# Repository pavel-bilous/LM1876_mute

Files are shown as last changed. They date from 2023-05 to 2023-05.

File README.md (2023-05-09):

# LM1876 mute delay

Circuit mutes LM1876 for 1 sec upon powering on. 

From the datasheet, if a logic high (1.5 to 5V) is applied to the MUTE pin, the amp will be muted.

The goal is to mute the amp during the turn on (and turn off). For that a logic high needs to be applied to the MUTE pin when amp is turned on, but after 1 or 2 seconds wait time the MUTE pin should be pulled low (< 1.5V).

Simple circuit that achieves the goal consists of:
* 5V zener regulator
* RC time delay
* NOT logic gate

Power is taken from the positive rail of the amp's power supply that is 20V to 25V.

Zener regulator resistor is selected at 10K, and it pulls ~2mA of current. Another 10K resistor is at the drain of the FET and pulls another ~2mA resulting in total current draw of ~4mA.

## PCB rendered in 3d:
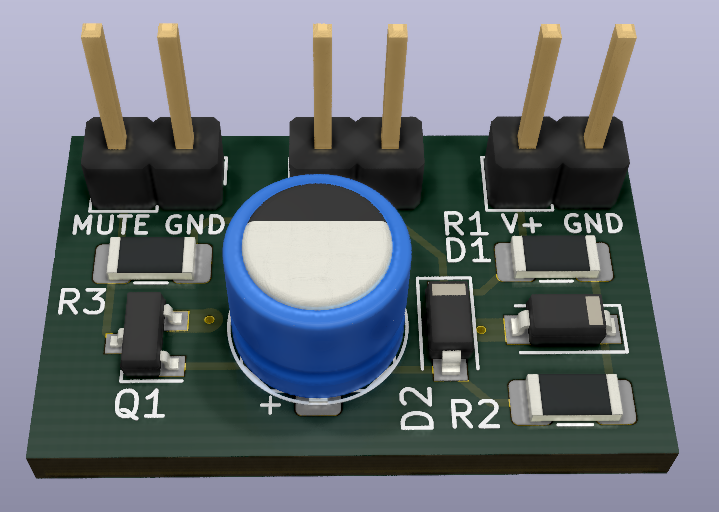
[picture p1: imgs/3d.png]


## Schematics
Only one 22uF capacitor needs to be used.
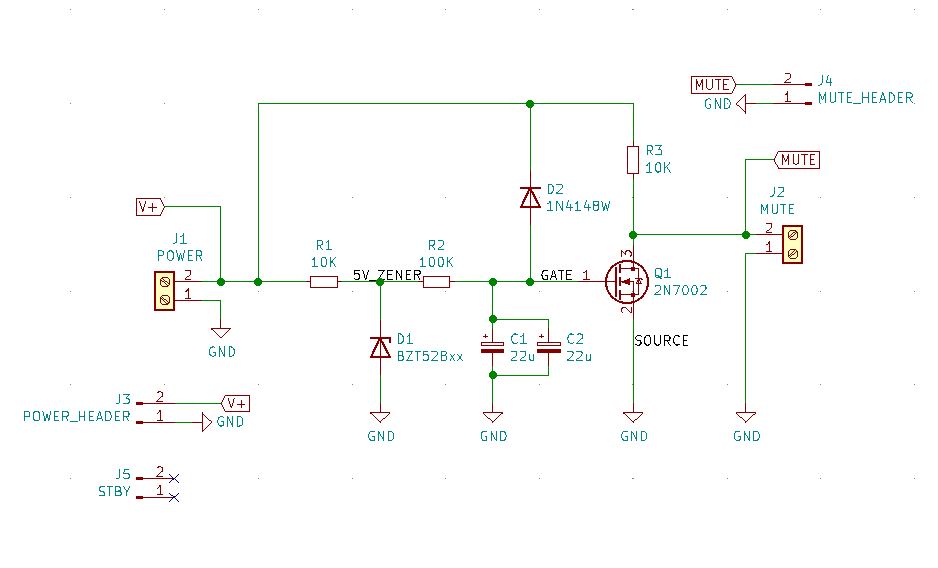
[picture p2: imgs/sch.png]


## PCB layout

Headers can be directly connected on top of the amplifier board in my other repository for LM1876 board.

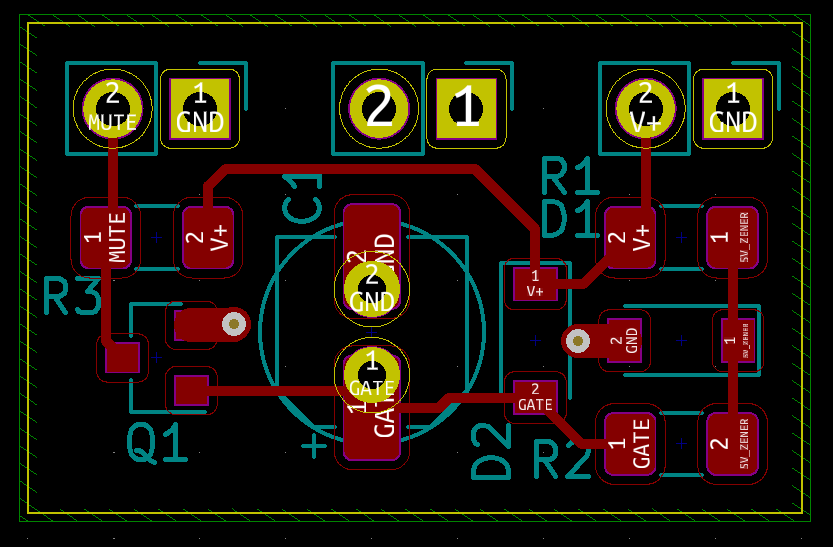
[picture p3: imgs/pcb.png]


## LTSpice simulation
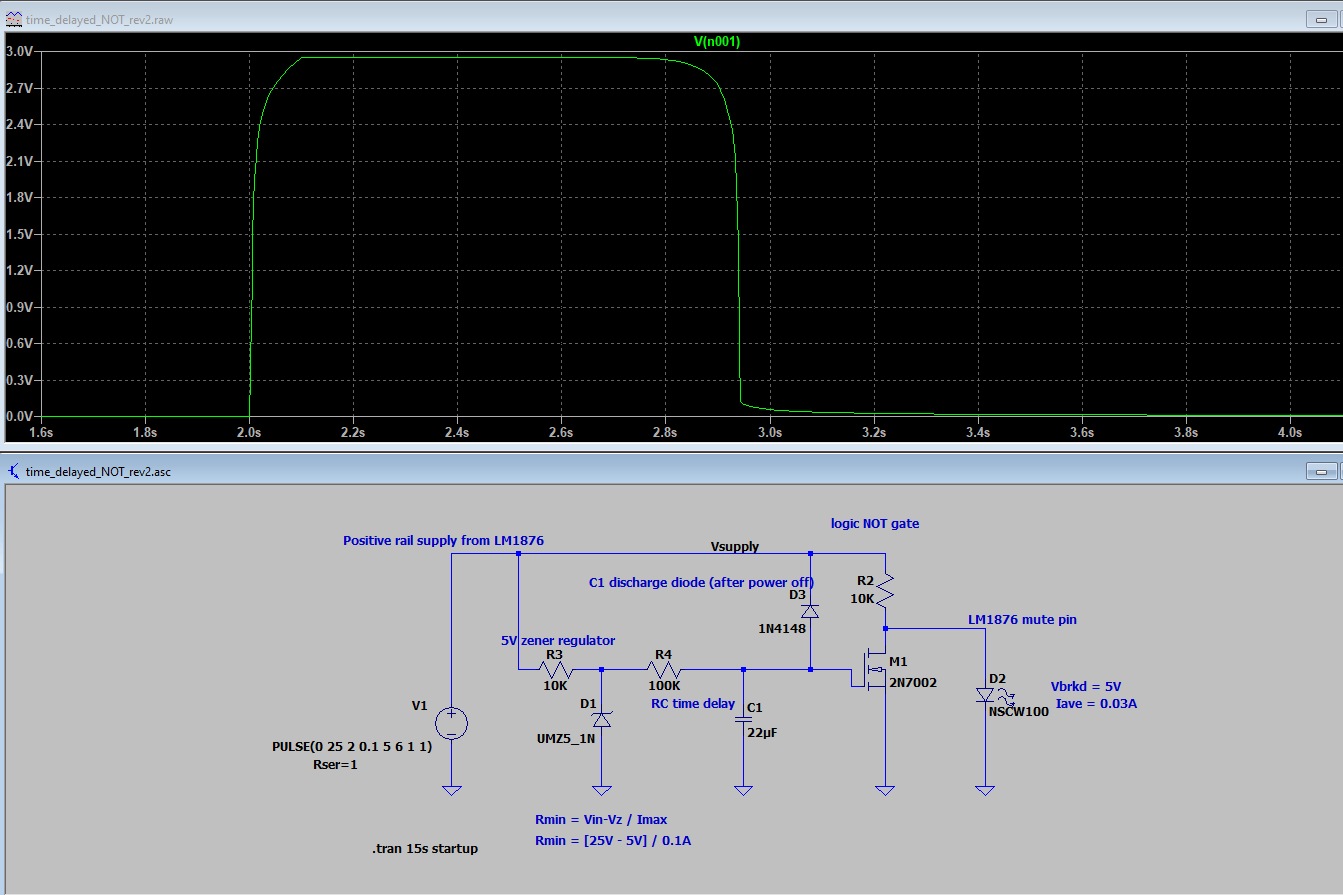
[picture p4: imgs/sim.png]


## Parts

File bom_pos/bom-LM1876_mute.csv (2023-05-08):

Id | Designator | Package | Quantity | Designation | Supplier and ref
1 | C2 | C_Radial_D6.3mm_H5.0mm_P2.50mm | 1 | 22u
2 | C1 | CP_Elec_5x5.4 | 1 | 22u
3 | J5 | PinHeader_1x02_P2.54mm_Vertical | 1 | STBY
4 | R3,R1 | R_1206_3216Metric_Pad1.42x1.75mm_HandSolder | 2 | 10K
5 | R2 | R_1206_3216Metric_Pad1.42x1.75mm_HandSolder | 1 | 100K
6 | Q1 | SOT-23 | 1 | 2N7002
7 | J4 | PinHeader_1x02_P2.54mm_Vertical | 1 | MUTE_HEADER
8 | J3 | PinHeader_1x02_P2.54mm_Vertical | 1 | POWER_HEADER
9 | D2 | D_SOD-123 | 1 | 1N4148W
10 | D1 | D_SOD-123 | 1 | BZT52Bxx

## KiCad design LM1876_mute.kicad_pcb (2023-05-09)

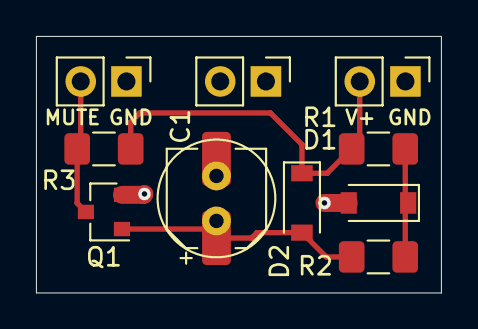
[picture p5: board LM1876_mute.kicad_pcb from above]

Board: 2 copper layers, 22.5 x 14.2 mm, 11 parts (0 on the bottom side), 5 nets.

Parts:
C1: 22u; CP_Elec_5x5.4
C2: 22u; C_Radial_D6.3mm_H5.0mm_P2.50mm
D1: BZT52Bxx; D_SOD-123
D2: 1N4148W; D_SOD-123
J3: POWER_HEADER; PinHeader_1x02_P2.54mm_Vertical
J4: MUTE_HEADER; PinHeader_1x02_P2.54mm_Vertical
J5: STBY; PinHeader_1x02_P2.54mm_Vertical
Q1: 2N7002; SOT-23
R1, R3: 10K; R_1206_3216Metric_Pad1.42x1.75mm_HandSolder
R2: 100K; R_1206_3216Metric_Pad1.42x1.75mm_HandSolder

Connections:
/5V_ZENER: D1.1, R1.1, R2.2
/GATE: C1.1, C2.1, D2.2, Q1.1, R2.1
GND: C1.2, C2.2, D1.2, J3.1, J4.1, Q1.2
MUTE: J4.2, Q1.3, R3.1
V+: D2.1, J3.2, R1.2, R3.2
